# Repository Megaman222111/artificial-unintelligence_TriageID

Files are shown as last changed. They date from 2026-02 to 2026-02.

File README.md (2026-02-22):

# TriageID

*Medical emergency information at a tap.*

20260222_011214 (1)
20260222_011007 (1)

## What it does

- **NFC bracelet + hub:** Patient wears a bracelet with a unique 15-character User ID. When tapped on the NFC scanner hub, the hub sends the ID over serial to the dashboard.
- **Doctor portal (web):** Clinics register at-risk patients and assign NFC bracelets. Patient data is stored encrypted; only the User ID lives on the tag (no PHI on the bracelet).
- **EMT dashboard:** Staff connect the NFC hub to their computer, open the dashboard, and tap a bracelet. They see patient info immediately, plus an AI summary and a risk/seriousness score from a trained model, all without on-the-spot rediagnosis.

---

## Project structure

| Path | Description |
|---|---|
| **webapp/** | Django API + Next.js frontend + risk model (backend, frontend, train script, artifacts). |
| **arduino_user_interface/** | Arduino (C++) firmware for the NFC hub: PN532 reader, 16x2 LCD, buzzer. Reads/writes User ID at 115200 baud. |
| **3D-print-models/** | STL files for the NFC scanner case and bracelet. |

---

## Tech stack (full project)

| Layer | Stack |
|---|---|
| **Hardware** | Arduino Nano, PN532 NFC module, 16x2 LCD, active buzzer; 3D-printed enclosure and bracelet |
| **Backend** | Django 5+, Python 3.11+; SQLite; JWT auth; encrypted patient storage |
| **Risk / AI** | scikit-learn (risk model trained on UCI diabetic dataset); Ark API for AI text overview (proof-of-concept) |
| **Frontend** | Next.js 16, React 19, TypeScript, Tailwind CSS, Radix UI; Web Serial API for NFC hub |
| **Firmware** | Arduino IDE, C++; PN532 (I2C/SPI), LiquidCrystal |

**Web app layout:** `webapp/config/` (Django settings), `webapp/accounts/` (doctor auth), `webapp/nfc_users/` (patients, NFC mapping, API, AI overview), `webapp/risk_scoring/` (features, training, service), `webapp/frontend/` (Next.js app).

---

## How to run the full project

### Prerequisites

- Python 3.11+
- Node.js 20+ and npm
- (Optional) NFC hub connected via USB for dashboard tap-to-read

---

### 1. Web app – Backend (Django)

From the repo root:

```bash
cd webapp
python -m venv .venv
# Windows:
.venv\Scripts\activate
# macOS/Linux:
source .venv/bin/activate

pip install -U pip
pip install -r requirements.txt
```

**Environment:** Create `webapp/.env`:

```env
AI_OVERVIEW_API_KEY=your_ark_api_key
AI_OVERVIEW_BASE_URL=https://api.ark-labs.cloud/api/v1
AI_OVERVIEW_MODEL=your_fast_model_name
```

(Do not wrap values in quotes. Optional if you only need risk scores.)

**Database:**

```bash
python manage.py migrate
```

**Create a doctor user (optional):**

```bash
python manage.py create_doctor doctor@example.com yourpassword --first-name "Doctor" --last-name "User"
```
---

### 2. Web app – Train the risk model

The seriousness/risk score uses a scikit-learn model trained on the UCI diabetic dataset. Run once (or after pulling new code/data):

```bash
# From webapp, with venv activated
python manage.py train_risk_model --min-rows 25 --min-positives 5 --max-rows 50000
```

- Training data: `webapp/risk_scoring/data/diabetic_data.csv`
- Artifacts: `webapp/risk_scoring/artifacts/risk_model_risk-v3-*.joblib`

Custom CSV:

```bash
python manage.py train_risk_model --csv-path /path/to/data.csv --max-rows 10000
```

Check which model is loaded:

```bash
python manage.py shell -c "from risk_scoring.service import RiskScoringService; print(RiskScoringService()._load_latest_model_payload().get('model_version'))"
```

---

### 3. Web app – Frontend (Next.js)

From the repo root:

```bash
cd webapp/frontend
npm install
```

Create `webapp/frontend/.env.local` if needed:

```env
NEXT_PUBLIC_DJANGO_API_BASE_URL=http://127.0.0.1:8000
```

---

### 4. Web app – Run backend and frontend

**Terminal 1 – backend:**

```bash
cd webapp
.venv\Scripts\activate   # Windows
# source .venv/bin/activate   # macOS/Linux
python manage.py runserver
```

**Terminal 2 – frontend:**

```bash
cd webapp/frontend
npm run dev
```

- API: http://127.0.0.1:8000  
- App: http://localhost:3000 (or the port Next.js shows)

---

### 5. NFC hub (Arduino)

- **Hardware:** Arduino Nano, PN532 (I2C), 16x2 LCD (4-bit), active buzzer. Wiring is in `arduino_user_interface/arduino_user_interface.ino`.
- **Library:** [PN532](https://github.com/elechouse/PN532) (e.g. PN532 + PN532_I2C in `Arduino/libraries`).
- **Upload:** Open the `.ino` in Arduino IDE, select board and port, upload.
- **Serial:** 115200 baud; commands `READ` or `WRITE|userid`; hub prints User ID when a tag is read.

---

### 6. Dashboard ↔ hub

In the web dashboard, use **Connect** to attach the hub via the browser’s Web Serial API (port is remembered in cookies). Tap a bracelet; the dashboard gets the User ID and fetches patient data and AI/risk results from the API.

---

## Inspiration and impact

Roughly **370,000 ED patients** experience serious harm from diagnostic errors each year. Early decisions by EMTs and nurses can be life-or-death; lack of prior patient information leads to bias and misdiagnosis. TriageID aims to give emergency staff **ready, rapid access** to curated, at-risk patient information and AI-assisted insights.

---

## What's next

Planned improvements from feedback:

- Run a local LLM for AI overview (instead of external API) for health security.
- Apple Watch / WearOS integration (NFC).
- Integration with NetCare (Alberta Health platform).
- Support multiple NFC bracelets per patient (e.g. if one is lost).

---

## Links
- **DevPost** [DevPost Link](https://devpost.com/software/triageid)
- **Video Demo** [Video Demo](https://youtu.be/T2ygs-dIF6k)
- **Pitch deck:** [TriageID Pitch Deck](https://pitch.com/v/triageid-pitch-deck-6bzk7b)
---

## Contributors

- Megh Mistry  
- Kulgagan Bajwa
- Hasish Karri  
- Hari Mallampalli

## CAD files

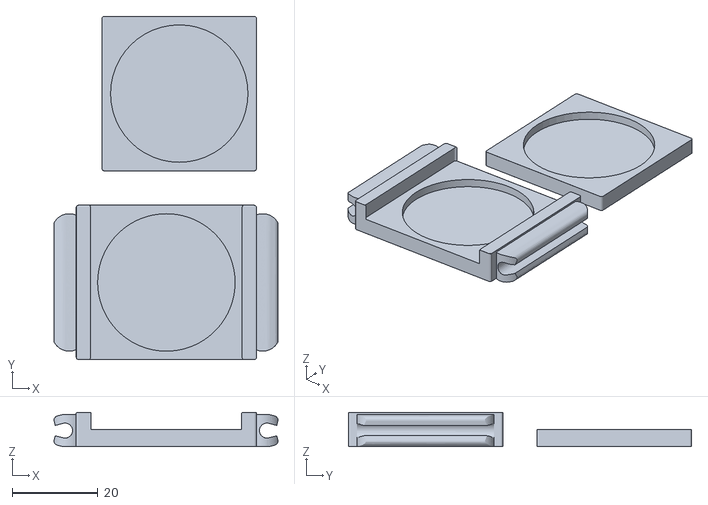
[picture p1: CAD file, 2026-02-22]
3D-print-models/watch-model.stl
52.2 x 80.0 x 8.00

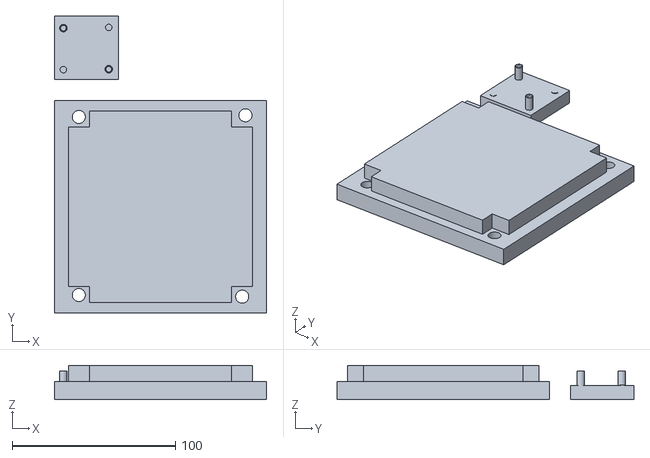
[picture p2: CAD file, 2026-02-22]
3D-print-models/NFC shield lid.stl
130.0 x 181.8 x 21.0

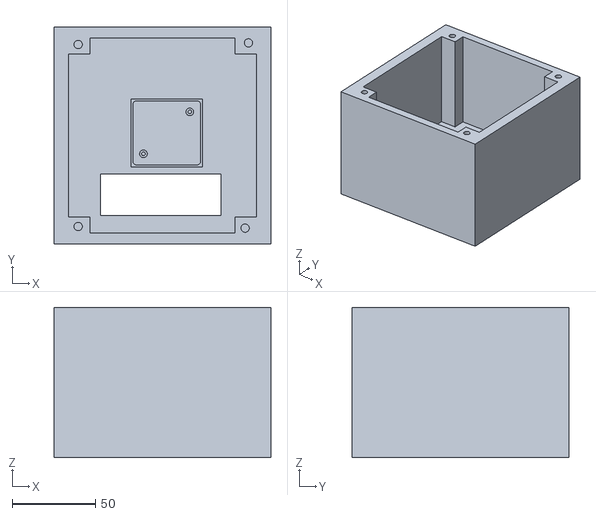
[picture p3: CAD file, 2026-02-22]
3D-print-models/NFC shield case.stl
130.0 x 130.0 x 90.0

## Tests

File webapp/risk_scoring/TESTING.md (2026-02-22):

# How to test risk scoring (CSV-trained model, DB inference)

All commands assume you are in the `webapp` directory.

## 1. Install dependencies

```bash
cd webapp
pip install -r requirements.txt
```

If you run frontend locally too:

```bash
cd webapp/frontend
npm install
```

## 2. Ensure training CSV exists

Default CSV path:

`webapp/risk_scoring/data/diabetic_data.csv`

Dataset used for supervised training:

- UCI Machine Learning Repository: *Diabetes 130-US hospitals for years 1999-2008*
- DOI: `10.24432/C5230J`
- Label: `readmitted == "<30"` (30-day deterioration/readmission proxy)

Model only uses features available in this app:

- `age_years` (from patient DOB)
- `days_since_admission`
- `medication_count` (from medications list length)
- `current_prescription_count`
- `allergy_count`
- `high_risk_allergy_count`
- `history_count` (from medical history list length)
- `high_risk_history_count`
- `past_history_count` (from past medical history list length)
- `high_risk_prescription_count`
- `gender`

## 3. Train model from CSV

```bash
cd webapp
python manage.py train_risk_model --min-rows 25 --min-positives 5 --max-rows 50000
```

Optional custom CSV path:

```bash
cd webapp
python manage.py train_risk_model --csv-path /absolute/path/to/diabetic_data.csv --max-rows 0
```

Output includes model version, row count, positives, and metrics.
Model artifact is saved in `webapp/risk_scoring/artifacts/risk_model_risk-v3-*.joblib`.

## 4. Test API risk scoring

Start Django:

```bash
cd webapp
python manage.py runserver
```

In another terminal:

```bash
API_BASE="http://127.0.0.1:8000"

PATIENT_ID=$(
  curl -s "$API_BASE/api/patients/" | python3 -c "import sys,json; d=json.load(sys.stdin); print(d[0]['id'] if d else '')"
)

if [ -z "$PATIENT_ID" ]; then
  echo "No patients found. Create one first, then retry."
else
  echo "Using patient_id=$PATIENT_ID"
  curl -s -X POST "$API_BASE/api/patients/risk-score/" \
    -H "Content-Type: application/json" \
    -d "{\"patient_id\":\"$PATIENT_ID\"}" | python3 -m json.tool
fi
```

You should get: `riskBand`, `riskProbability`, `modelVersion`, `topFactors`, `scoringMode`, `seriousnessFactor`, `seriousnessLevel`, `assessmentRecommendation`.

## 5. Full stack check

Backend:

```bash
cd webapp
python manage.py runserver
```

Frontend:

```bash
cd webapp/frontend
npm run dev
```

Open a patient in the UI and verify risk data is displayed.

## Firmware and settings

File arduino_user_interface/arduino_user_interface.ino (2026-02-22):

/*
 * PN532 NFC – User ID read/write interface
 *
 * Uses elechouse/PN532 library: https://github.com/elechouse/PN532
 * Install: download ZIP, extract PN532, PN532_I2C (or PN532_SPI) into Arduino/libraries.
 *
 * Supports:
 *   - Mifare Classic 1K (4-byte UID): user ID in block 4 (sector 1)
 *   - Mifare Ultralight / NTAG (7-byte UID): user ID in pages 4–7
 *
 * ========== WIRING (PN532 I2C) ==========
 *   Arduino A4 (SDA)  ->  PN532 SDA
 *   Arduino A5 (SCL)  ->  PN532 SCL
 *   Arduino 5V        ->  PN532 VCC   (or 3.3V if module is 3.3V-only)
 *   Arduino GND       ->  PN532 GND
 *
 * ========== WIRING (1602 LCD, 4-bit) ==========
 *   LCD pin   ->   Arduino
 *   --------      --------
 *   VSS       ->   GND
 *   VDD       ->   5V
 *   VO        ->   Digital 6 (PWM contrast) or 10k pot: middle=VO, ends=5V & GND
 *   RS        ->   Digital 12
 *   R/W       ->   GND
 *   E         ->   Digital 11
 *   D4        ->   Digital 5
 *   D5        ->   Digital 4
 *   D6        ->   Digital 3
 *   D7        ->   Digital 2
 *   A         ->   5V (backlight +)
 *   K         ->   GND (backlight -)
 *
 * ========== BUZZER (active) ==========
 *   Buzzer +  ->  Digital 8  (or BUZZER_PIN below)
 *   Buzzer -  ->  GND
 *   If no sound: try swapping wires, or set BUZZER_ACTIVE_LOW to 1 below.
 *
 * For SPI PN532: set USE_I2C to 0; then SS=10, SCK=13, MOSI=11, MISO=12.
 */

#include <Wire.h>
#include <string.h>
#include <PN532_I2C.h>
#include <PN532.h>
#include <LiquidCrystal.h> 

int Contrast=75;
LiquidCrystal lcd(12, 11, 5, 4, 3, 2);  

// ---- Connection: set to 1 for I2C, 0 for SPI ----
#define USE_I2C 1

#if USE_I2C
  PN532_I2C pn532i2c(Wire);
  PN532 nfc(pn532i2c);
#else
  #include <SPI.h>
  #include <PN532_SPI.h>
  #define PN532_SS 10
  PN532_SPI pn532spi(SPI, PN532_SS);
  PN532 nfc(pn532spi);
#endif

// Mifare default key (factory default for many cards)
const uint8_t MIFARE_KEY_DEFAULT[6] = { 0xFF, 0xFF, 0xFF, 0xFF, 0xFF, 0xFF };

// User ID is stored in one block (16 bytes). Max printable length = 15 + null.
#define USER_ID_MAX_LEN  16
#define MIFARE_CLASSIC_USER_BLOCK  4   // first data block of sector 1
#define MIFARE_ULTRALIGHT_USER_PAGE 4  // first writable page (4–7 = 16 bytes)

// Menu
#define MODE_READ  1
#define MODE_WRITE 2
int menuMode = MODE_READ;

// Web app / serial protocol: "READ" or "WRITE|userid" (one line, 115200 baud)
#define CMD_BUF_LEN 32
char cmdBuf[CMD_BUF_LEN];
uint8_t cmdBufIdx = 0;
#define CARD_WAIT_MS 60000  // max time to wait for card when in command mode
#define COUNTDOWN_SECONDS 3 // seconds to wait between consecutive scans (LCD countdown)

#define BUZZER_PIN 8
// Set to 1 only if your buzzer beeps when the pin is LOW (default 0 = beep when HIGH)
#define BUZZER_ACTIVE_LOW 0
#if BUZZER_ACTIVE_LOW
  #define BUZZER_ON   LOW
  #define BUZZER_OFF  HIGH
#else
  #define BUZZER_ON   HIGH
  #define BUZZER_OFF  LOW
#endif

void beepSuccess() {
  digitalWrite(BUZZER_PIN, BUZZER_ON);
  delay(50);
  digitalWrite(BUZZER_PIN, BUZZER_OFF);
}

void beepError() {
  digitalWrite(BUZZER_PIN, BUZZER_ON);
  delay(80);
  digitalWrite(BUZZER_PIN, BUZZER_OFF);
}

static bool userIDIsEmpty(const char* id) {
  if (!id) return true;
  for (int i = 0; i < USER_ID_MAX_LEN - 1 && id[i]; i++)
    if (id[i] != ' ') return false;
  return true;
}

// LCD mode: show "Reading" or "Writing" only
static int lcdDisplayMode = MODE_READ;

void lcdShowReading() {
  lcdDisplayMode = MODE_READ;
  lcd.clear();
  lcd.setCursor(0, 0);
  lcd.print(F("Reading"));
}

void lcdShowWriting() {
  lcdDisplayMode = MODE_WRITE;
  lcd.clear();
  lcd.setCursor(0, 0);
  lcd.print(F("Writing"));
}

void lcdShowIdle() {
  if (lcdDisplayMode == MODE_WRITE)
    lcdShowWriting();
  else
    lcdShowReading();
}

void lcdShowError(const char* msg) {
  lcd.clear();
  lcd.setCursor(0, 0);
  lcd.print(F("Error"));
  lcd.setCursor(0, 1);
  if (msg)
    for (int i = 0; i < 16 && msg[i]; i++)
      lcd.print(msg[i]);
}

// Show countdown on LCD between consecutive scans (e.g. "Next scan in 3" ... "1")
void lcdCountdownSeconds(int seconds) {
  for (int i = seconds; i >= 1; i--) {
    lcd.clear();
    lcd.setCursor(0, 0);
    lcd.print(F("Next scan in"));
    lcd.setCursor(0, 1);
    lcd.print(i);
    delay(1000);
  }
  lcdShowIdle();
}

// Run when PN532 not found: scan I2C bus and print tips
void scanI2CAndHalt() {
  Serial.println(F("Scanning I2C bus (SDA=A4, SCL=A5 on Uno/Nano)..."));
  uint8_t count = 0;
  for (uint8_t addr = 1; addr < 127; addr++) {
    Wire.beginTransmission(addr);
    if (Wire.endTransmission() == 0) {
      Serial.print(F("  Device at 0x")); Serial.println(addr, HEX);
      count++;
    }
    delay(5);
  }
  if (count == 0)
    Serial.println(F("  No I2C devices found."));
  Serial.println();
  Serial.println(F("Check:"));
  Serial.println(F("  - VCC to 3.3V or 5V, GND to GND"));
  Serial.println(F("  - SDA -> A4 (Uno/Nano), SCL -> A5"));
  Serial.println(F("  - Some boards: SDA/SCL are different (e.g. Mega 20/21)"));
  Serial.println(F("  - Try 0.5s delay: unplug USB, plug back, open Serial Monitor"));
  while (1) { delay(100); }
}

void setup() {
  Serial.begin(115200);
  while (!Serial) { delay(10); }

  Serial.println(F("PN532 User ID – Read/Write (elechouse/PN532)"));
  Serial.println();

#if USE_I2C
  Wire.begin();
  delay(400);   // let PN532 power up
#endif

  nfc.begin();

  uint32_t v = nfc.getFirmwareVersion();
  if (!v) {
    Serial.println(F("PN532 not found. Check wiring (I2C/SPI)."));
#if USE_I2C
    scanI2CAndHalt();
#else
    Serial.println(F("Check SPI: SS=10, SCK=13, MOSI=11, MISO=12."));
    while (1) { delay(100); }
#endif
  }
  Serial.print(F("PN5")); Serial.print((v >> 24) & 0xFF, HEX);
  Serial.print(F(" firmware ")); Serial.print((v >> 16) & 0xFF, DEC);
  Serial.print('.'); Serial.println((v >> 8) & 0xFF, DEC);

  nfc.SAMConfig();

  delay(200);
  lcd.begin(16, 2);
  pinMode(6, OUTPUT);
  analogWrite(6, Contrast);
  pinMode(BUZZER_PIN, OUTPUT);
  digitalWrite(BUZZER_PIN, BUZZER_OFF);
  lcd.clear();
  lcdShowReading();

  printMenu();
}

// After read: show reading then countdown
void lcdUserReadAndCountdown(const char* userid) {
  (void)userid;
  lcdShowReading();
  lcdCountdownSeconds(COUNTDOWN_SECONDS);
}

// After write: show writing then countdown
void lcdCountdown() {
  lcdShowWriting();
  lcdCountdownSeconds(COUNTDOWN_SECONDS);
}

// Wait for card; return true and set uid/uidLen, or false on timeout
// Use a longer per-poll timeout (800ms) so the reader has time to detect the card
bool waitForCard(uint8_t *uid, uint8_t *uidLen, uint32_t timeoutMs) {
  unsigned long start = millis();
  while (millis() - start < timeoutMs) {
    if (nfc.readPassiveTargetID(PN532_MIFARE_ISO14443A, uid, uidLen, 800))
      return true;
    delay(30);
  }
  return false;
}

// Get user ID string from a 16-byte block (null-terminated, max 15 chars)
void userIDFromBlock(uint8_t *block, char *out) {
  block[USER_ID_MAX_LEN - 1] = '\0';
  strncpy(out, (char*)block, USER_ID_MAX_LEN - 1);
  out[USER_ID_MAX_LEN - 1] = '\0';
}

// Fill 16-byte block from user ID string (zero-padded)
void blockFromUserID(const char *id, uint8_t *block) {
  int i = 0;
  while (i < USER_ID_MAX_LEN - 1 && id[i]) {
    block[i] = (uint8_t)id[i];
    i++;
  }
  while (i < USER_ID_MAX_LEN) block[i++] = 0;
}

// Protocol: READ -> WAITING, then OK|READ|userid or ERROR|msg
void doReadCommand() {
  lcdShowReading();
  Serial.println(F("WAITING"));
  uint8_t uid[8];
  uint8_t uidLen = 0;
  if (!waitForCard(uid, &uidLen, CARD_WAIT_MS)) {
    Serial.println(F("ERROR|Timeout waiting for card"));
    beepError();
    lcdShowError("Timeout");
    delay(3000);
    lcdShowIdle();
    return;
  }
  char userid[USER_ID_MAX_LEN];
  uint8_t block[16];
  if (uidLen == 4) {
    if (!nfc.mifareclassic_AuthenticateBlock(uid, uidLen, MIFARE_CLASSIC_USER_BLOCK, 0, (uint8_t*)MIFARE_KEY_DEFAULT)) {
      Serial.println(F("ERROR|Auth failed"));
      beepError();
      lcdShowError("Auth failed");
      delay(3000);
      lcdShowIdle();
      return;
    }
    if (!nfc.mifareclassic_ReadDataBlock(MIFARE_CLASSIC_USER_BLOCK, block)) {
      Serial.println(F("ERROR|Read failed"));
      beepError();
      lcdShowError("Read failed");
      delay(3000);
      lcdShowIdle();
      return;
    }
  } else if (uidLen == 7) {
    for (int i = 0; i < 4; i++) {
      if (!nfc.mifareultralight_ReadPage(MIFARE_ULTRALIGHT_USER_PAGE + i, block + i * 4)) {
        Serial.println(F("ERROR|Read failed"));
        beepError();
        lcdShowError("Read failed");
        delay(3000);
        lcdShowIdle();
        return;
      }
    }
  } else {
    Serial.println(F("ERROR|Unsupported card"));
    beepError();
    lcdShowError("Unsupported card");
    delay(3000);
    lcdShowIdle();
    return;
  }
  userIDFromBlock(block, userid);
  Serial.print(F("OK|READ|"));
  Serial.println(userid);
  beepSuccess();
  lcdUserReadAndCountdown(userid);
}

// Protocol: WRITE|id -> WAITING, then OK|WRITE or ERROR|msg
void doWriteCommand(const char *id) {
  lcdShowWriting();
  Serial.println(F("WAITING"));
  uint8_t uid[8];
  uint8_t uidLen = 0;
  if (!waitForCard(uid, &uidLen, CARD_WAIT_MS)) {
    Serial.println(F("ERROR|Timeout waiting for card"));
    beepError();
    lcdShowError("Timeout");
    delay(3000);
    lcdShowIdle();
    return;
  }
  uint8_t block[16];
  blockFromUserID(id, block);
  if (uidLen == 4) {
    if (!nfc.mifareclassic_AuthenticateBlock(uid, uidLen, MIFARE_CLASSIC_USER_BLOCK, 0, (uint8_t*)MIFARE_KEY_DEFAULT)) {
      Serial.println(F("ERROR|Auth failed"));
      beepError();
      lcdShowError("Auth failed");
      delay(3000);
      lcdShowIdle();
      return;
    }
    if (!nfc.mifareclassic_WriteDataBlock(MIFARE_CLASSIC_USER_BLOCK, block)) {
      Serial.println(F("ERROR|Write failed"));
      beepError();
      lcdShowError("Write failed");
      delay(3000);
      lcdShowIdle();
      return;
    }
  } else if (uidLen == 7) {
    for (int i = 0; i < 4; i++) {
      if (!nfc.mifareultralight_WritePage(MIFARE_ULTRALIGHT_USER_PAGE + i, block + i * 4)) {
        Serial.println(F("ERROR|Write failed"));
        beepError();
        lcdShowError("Write failed");
        delay(3000);
        lcdShowIdle();
        return;
      }
    }
  } else {
    Serial.println(F("ERROR|Unsupported card"));
    beepError();
    lcdShowError("Unsupported card");
    delay(3000);
    lcdShowIdle();
    return;
  }
  Serial.println(F("OK|WRITE"));
  beepSuccess();
  lcdCountdown();
}

void loop() {
  // ---- Serial command buffer (for web app: READ / WRITE|id) ----
  while (Serial.available()) {
    char c = Serial.read();
    if (c == '\n' || c == '\r') {
      cmdBuf[cmdBufIdx] = '\0';
      if (cmdBufIdx > 0) {
        if (strcmp(cmdBuf, "READ") == 0) {
          doReadCommand();
        } else if (strcmp(cmdBuf, "WRITE") == 0 || strncmp(cmdBuf, "WRITE|", 6) == 0) {
          const char *id = (strncmp(cmdBuf, "WRITE|", 6) == 0) ? (cmdBuf + 6) : "";
          char trimId[USER_ID_MAX_LEN];
          int i = 0;
          while (i < USER_ID_MAX_LEN - 1 && id[i]) { trimId[i] = id[i]; i++; }
          trimId[i] = '\0';
          doWriteCommand(trimId);
        } else if (cmdBuf[0] == '1' && cmdBufIdx == 1) {
          menuMode = MODE_READ;
          printMenu();
        } else if (cmdBuf[0] == '2' && cmdBufIdx == 1) {
          menuMode = MODE_WRITE;
          printMenu();
        }
      }
      cmdBufIdx = 0;
      return;
    }
    if (cmdBufIdx < CMD_BUF_LEN - 1)
      cmdBuf[cmdBufIdx++] = c;
  }

  // ---- Menu mode: wait for card ----
  uint8_t uid[8];
  uint8_t uidLen;

  if (!nfc.readPassiveTargetID(PN532_MIFARE_ISO14443A, uid, &uidLen, 200))
    return;

  // Card present (Serial Monitor mode)
  Serial.println(F("\n--- Card detected ---"));
  Serial.print(F("UID (")); Serial.print(uidLen); Serial.print(F(" bytes): "));
  nfc.PrintHex(uid, uidLen);
  Serial.println();

  bool readOk = true;
  if (uidLen == 4) {
    if (menuMode == MODE_READ)
      readOk = readUserIDClassic(uid, uidLen);
    else
      writeUserIDClassic(uid, uidLen);
  } else if (uidLen == 7) {
    if (menuMode == MODE_READ)
      readOk = readUserIDUltralight();
    else
      writeUserIDUltralight();
  } else {
    Serial.println(F("Card type not supported (need 4- or 7-byte UID)."));
  }

  Serial.println(F("--- Remove card ---\n"));
  if (!readOk) {
    delay(1500);
    lcdCountdownSeconds(COUNTDOWN_SECONDS);
    lcdShowIdle();
  } else {
    lcdCountdownSeconds(COUNTDOWN_SECONDS);
  }
  printMenu();
}

void printMenu() {
  Serial.println(F("Options: 1 = Read user ID  2 = Write user ID"));
  Serial.print(F("Current mode: "));
  Serial.println(menuMode == MODE_READ ? F("READ") : F("WRITE"));
  Serial.println(F("Present a card..."));
}

// ---- Mifare Classic: block 4 (sector 1) ----
bool readUserIDClassic(uint8_t *uid, uint8_t uidLen) {
  if (!nfc.mifareclassic_AuthenticateBlock(uid, uidLen, MIFARE_CLASSIC_USER_BLOCK,
                                           0, (uint8_t*)MIFARE_KEY_DEFAULT)) {
    Serial.println(F("Auth failed (wrong key?)."));
    return false;
  }

  uint8_t block[16];
  if (!nfc.mifareclassic_ReadDataBlock(MIFARE_CLASSIC_USER_BLOCK, block)) {
    Serial.println(F("Read block failed."));
    return false;
  }

  printUserIDFromBlock(block);
  char uidStr[USER_ID_MAX_LEN];
  userIDFromBlock(block, uidStr);
  beepSuccess();
  lcdShowReading();
  return true;
}

void writeUserIDClassic(uint8_t *uid, uint8_t uidLen) {
  lcdShowWriting();
  if (!nfc.mifareclassic_AuthenticateBlock(uid, uidLen, MIFARE_CLASSIC_USER_BLOCK,
                                           0, (uint8_t*)MIFARE_KEY_DEFAULT)) {
    Serial.println(F("Auth failed (wrong key?)."));
    beepError();
    lcdShowError("Auth failed");
    delay(3000);
    lcdShowIdle();
    return;
  }

  uint8_t block[16];
  if (!getUserIDFromSerial(block)) return;

  if (!nfc.mifareclassic_WriteDataBlock(MIFARE_CLASSIC_USER_BLOCK, block)) {
    Serial.println(F("Write block failed."));
    beepError();
    lcdShowError("Write failed");
    delay(3000);
    lcdShowIdle();
    return;
  }
  Serial.println(F("User ID written."));
  beepSuccess();
  lcdShowWriting();
}

// ---- Mifare Ultralight: pages 4–7 (16 bytes) ----
bool readUserIDUltralight() {
  uint8_t block[16];
  for (int i = 0; i < 4; i++) {
    if (!nfc.mifareultralight_ReadPage(MIFARE_ULTRALIGHT_USER_PAGE + i, block + i * 4)) {
      Serial.println(F("Read page failed."));
      return false;
    }
  }
  printUserIDFromBlock(block);
  char uidStr[USER_ID_MAX_LEN];
  userIDFromBlock(block, uidStr);
  beepSuccess();
  lcdShowReading();
  return true;
}

void writeUserIDUltralight() {
  lcdShowWriting();
  uint8_t block[16];
  if (!getUserIDFromSerial(block)) return;

  for (int i = 0; i < 4; i++) {
    if (!nfc.mifareultralight_WritePage(MIFARE_ULTRALIGHT_USER_PAGE + i, block + i * 4)) {
      Serial.println(F("Write page failed."));
      beepError();
      lcdShowError("Write failed");
      delay(3000);
      lcdShowIdle();
      return;
    }
  }
  Serial.println(F("User ID written."));
  beepSuccess();
  lcdShowWriting();
}

// ---- Helpers ----
void printUserIDFromBlock(uint8_t *block) {
  block[USER_ID_MAX_LEN - 1] = '\0'; // ensure null
  Serial.print(F("User ID: \""));
  Serial.print((char*)block);
  Serial.println(F("\""));
}

bool getUserIDFromSerial(uint8_t *block) {
  Serial.print(F("Enter user ID (max "));
  Serial.print(USER_ID_MAX_LEN - 1);
  Serial.println(F(" chars), then Enter:"));

  // Clear any leftover
  while (Serial.available()) Serial.read();

  int idx = 0;
  unsigned long start = millis();
  while (idx < USER_ID_MAX_LEN) {
    if (Serial.available()) {
      char c = Serial.read();
      if (c == '\n' || c == '\r') break;
      block[idx++] = (uint8_t)c;
    }
    if (millis() - start > 10000) {
      Serial.println(F("Timeout."));
      return false;
    }
    delay(10);
  }

  // Pad rest with zeros
  while (idx < USER_ID_MAX_LEN)
    block[idx++] = 0;

  Serial.print(F("Writing: \""));
  block[USER_ID_MAX_LEN - 1] = '\0';
  Serial.print((char*)block);
  Serial.println(F("\""));
  block[USER_ID_MAX_LEN - 1] = 0;
  return true;
}

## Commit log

2026-02-21 model refactor, working with current user
2026-02-22 arduino chances
2026-02-22 hopefully final commit <fingers crossed> :)
2026-02-22 Adding 3D-print stl files
    [NFC shield case.stl, NFC shield lid.stl]
2026-02-22 adding final .stl file
    [watch-model.stl]
